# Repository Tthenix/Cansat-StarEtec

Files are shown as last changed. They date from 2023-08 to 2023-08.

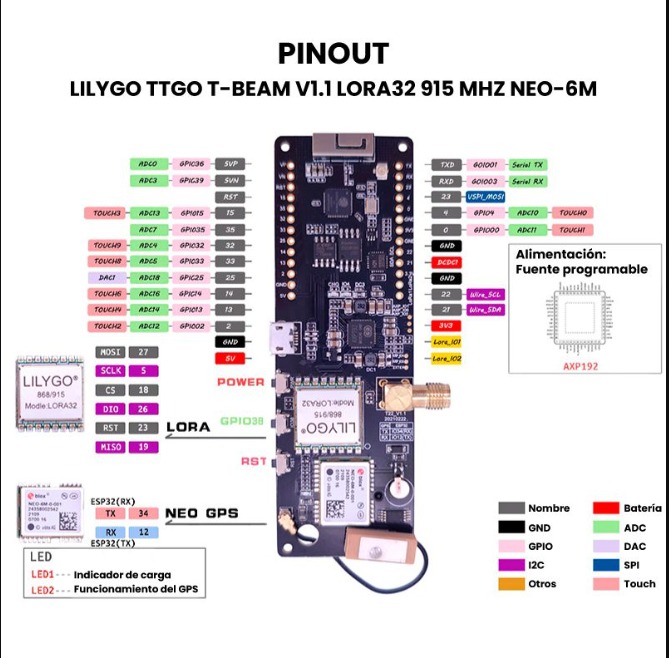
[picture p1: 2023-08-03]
T-beam/lilygo T beam documentos/Lilygo T beam Pinout.jpg

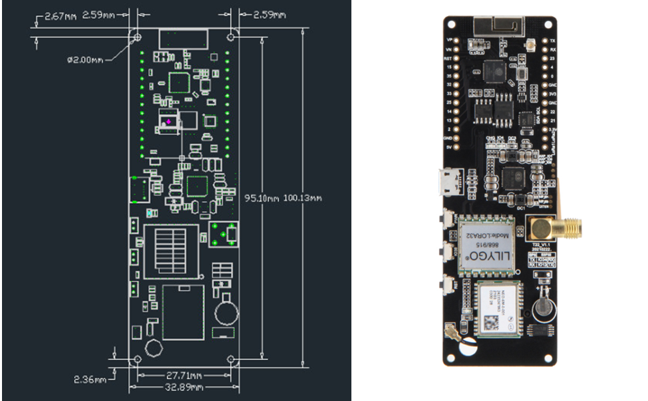
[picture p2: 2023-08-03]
T-beam/lilygo T beam documentos/size_LilygoTbeam.jpg

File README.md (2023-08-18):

# Cansat StarEtec

¡Bienvenido al repositorio del proyecto Cansat StarEtec! Este proyecto trata sobre la construcción y lanzamiento de un Cansat, que es una simulación de una misión espacial en una lata. Este repositorio contiene el código, el diseño y la documentación relacionados con el proyecto. El mismo es fue desarrollado por estudiantes del colegio técnico de la Universidad de Mendoda (UM), también conocido cómo ETec.
Para más información puede acercarse por la pagina web del proyecto [en google sites](https://sites.google.com/alumno.etec.um.edu.ar/cansat-2023/inicio)

## Descripción del Proyecto

El objetivo principal de este proyecto es desarrollar y lanzar con éxito un Cansat, recopilando datos y realizando diferentes experimentos durante su descenso desde una cierta altura. Estos son los aspectos clave del proyecto:

- Diseño y construcción del hardware del Cansat.
- Desarrollo del código necesario para la recopilación de datos y el control del Cansat.
- Pruebas y ajustes del Cansat antes del lanzamiento.
- Lanzamiento y recopilación de datos durante el descenso.
- Análisis de los datos y conclusiones obtenidas.

## Estructura del Repositorio

El repositorio está organizado de la siguiente manera:

- `docs/`: Esta carpeta contiene la documentación del proyecto, incluyendo manuales, guías y otros recursos útiles.
- `T-beam/`: Aquí encontrarás el código fuente relacionado con la parte encargada de recopilar información del medio y enviarla.
- `diseño3D/`: Contiene los diseños 3D del Cansat.
- `esp32cam_usd_uart/`: Aquí encontrarás el código fuente relacionado el sistema de recopilación de imágenes.
- `receiver_Heltec/`: Aquí encontrarás el código fuente relacionado con la parte encargada de recopilar información enviada y copmunicarse con el ordenador.
- `script/`: Aquí encontrarás el código fuente relacionado con la parte encargada de interpretar los datos, mostrarlos y guardarlos en archivos .csv convenientes.

## Cómo Contribuir

¡Agradecemos tus contribuciones al proyecto! Si deseas contribuir, puedes seguir estos pasos:

1. Haz un `fork` de este repositorio.
2. Clona tu fork en tu máquina local: `git clone https://github.com/TuUsuario/Cansat-StarEtec.git`
3. Crea una nueva rama para tu contribución: `git checkout -b nueva-funcionalidad`
4. Realiza tus cambios y mejoras.
5. Realiza commits con mensajes descriptivos: `git commit -m "Añadida nueva funcionalidad: X"`
6. Sube tus cambios a tu fork: `git push origin nueva-funcionalidad`
7. Abre un Pull Request en este repositorio.

## Contacto

Si tienes preguntas, sugerencias o comentarios, puedes ponerte en contacto con nosotros visitando [nuestra pagina web](https://sites.google.com/alumno.etec.um.edu.ar/cansat-2023/inicio).
También están los siguientes correos:
- Docente Colaborador: [`Mario Stefano Papetti Funes`](mailto:mario.papetti@etec.um.edu.ar).
- Docente Colaborador: [`Gema Pont`](mailto:maria.pont@etec.um.edu.ar).
- Alumno Colaborador: [`Nahuel Quiroga`](mailto:n.quiroga@alumno.etec.um.edu.ar).
- Integrante de equipo: [`Mercedes Marón`](mailto:m.maron@alumno.um.edu.ar).
- Integrante de equipo: [`Santiago Juárez`](mailto:sc.juarez@alumno.etec.um.edu.ar).
- Integrante de equipo: [`Mateo Molina`](mailto:mn.molina@alumno.etec.um.edu.ar).

---

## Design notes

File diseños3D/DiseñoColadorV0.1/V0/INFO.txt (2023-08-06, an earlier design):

By:Lucas Adriano Perinetti
Primer diseño
Ventajas: Resistente
Desventajas: Pesa demasiado, No se tuvo en cuenta el BMP280

Las ideas partieron de un diseño cilindrico el cual se armo y se le hicieron ajugueros para los sensores, tambien se diseño una tapa para el cilindro y una estructura interna

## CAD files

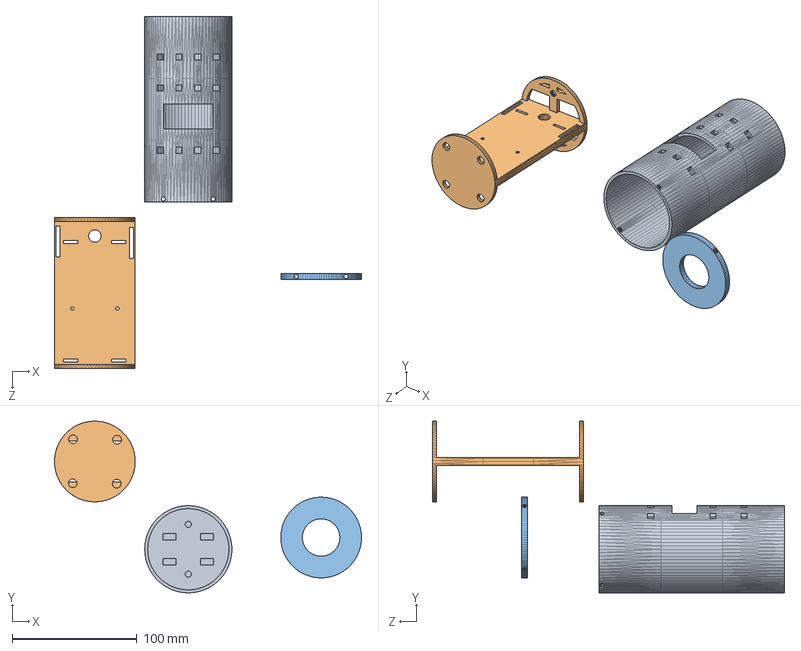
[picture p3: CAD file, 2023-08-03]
diseños3D/v0-4/Ensamblaje.SLDASM
246.5 x 137.8 x 282.7 mm
Envase
Interior
Tapa

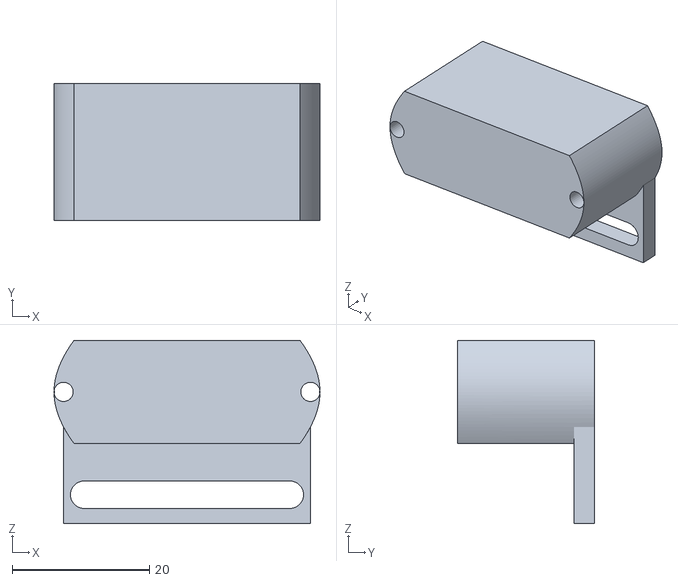
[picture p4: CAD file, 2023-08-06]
diseños3D/DiseñoColadorV0.1/V2/Soporte Lidar Y Ov7670 .stl
38.8 x 20.0 x 26.7

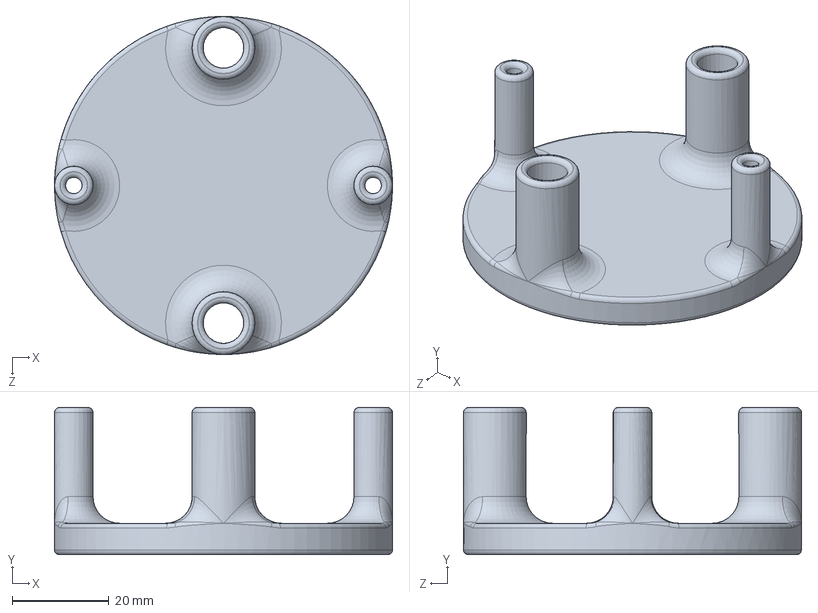
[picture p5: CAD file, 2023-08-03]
diseños3D/v0-3/Base.SLDPRT
70.0 x 30.5 x 70.0 mm

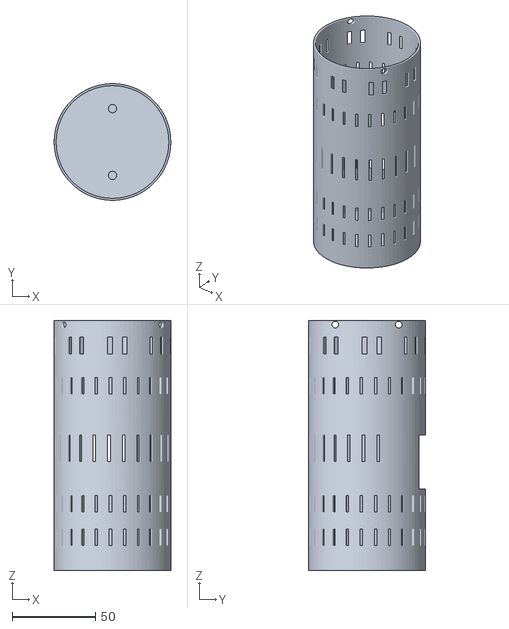
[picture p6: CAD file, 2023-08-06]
diseños3D/DiseñoColadorV0.1/V2/Envase.stl
70.0 x 70.0 x 150.0

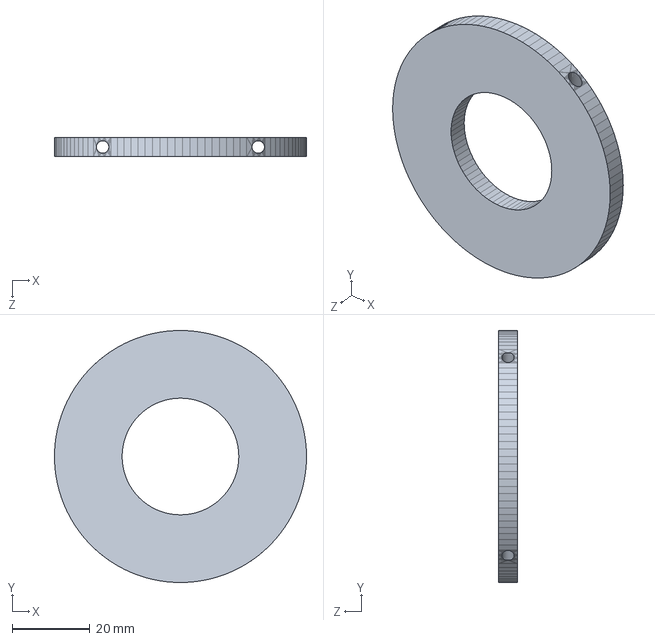
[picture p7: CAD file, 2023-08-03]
diseños3D/v0-4/Tapa.SLDPRT
64.8 x 64.8 x 5.00 mm

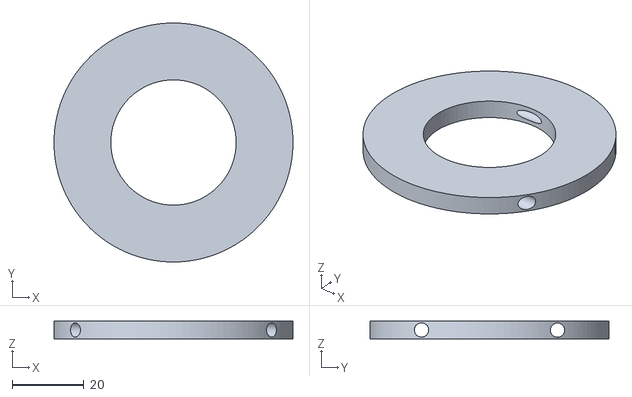
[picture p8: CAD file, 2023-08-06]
diseños3D/DiseñoColadorV0.1/V2/Tapa.stl
66.8 x 66.8 x 5.00

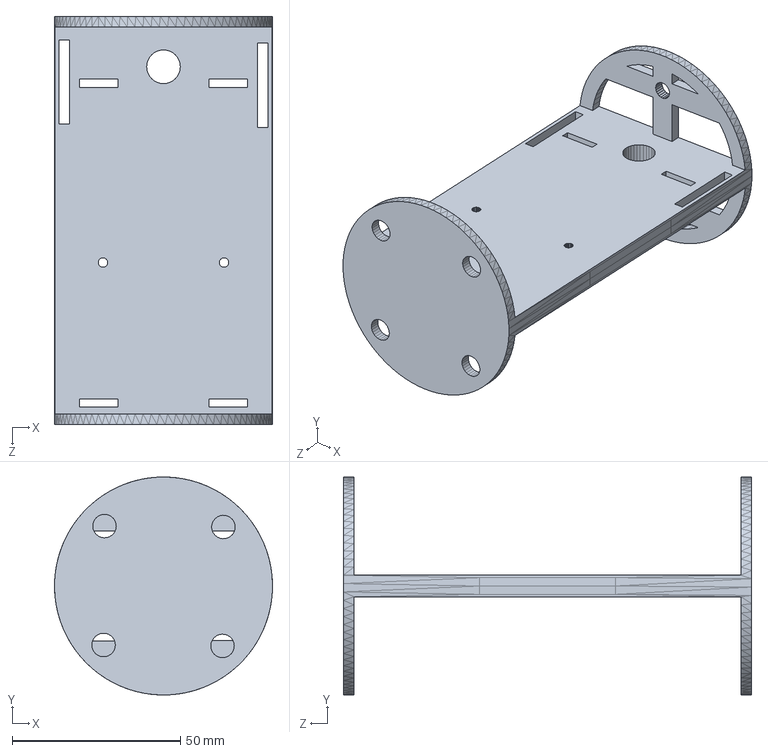
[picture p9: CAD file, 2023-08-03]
diseños3D/v0-4/Interior.SLDPRT
64.8 x 64.8 x 121.4 mm

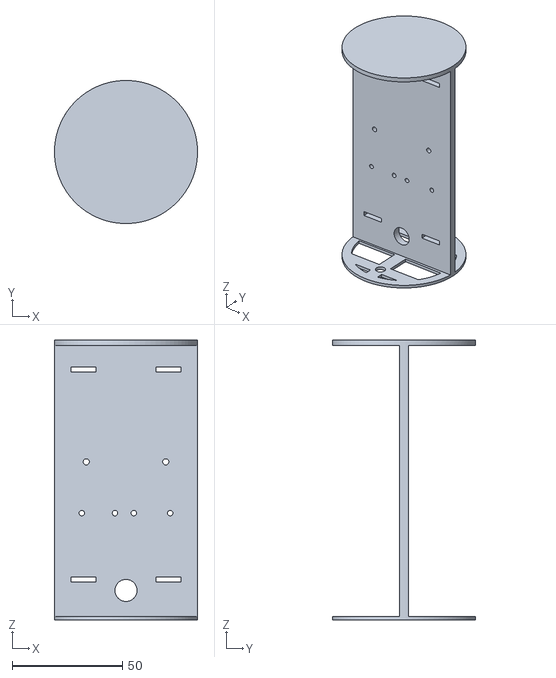
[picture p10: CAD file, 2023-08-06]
diseños3D/DiseñoColadorV0.1/V2/Interno.stl
64.8 x 64.8 x 126.8

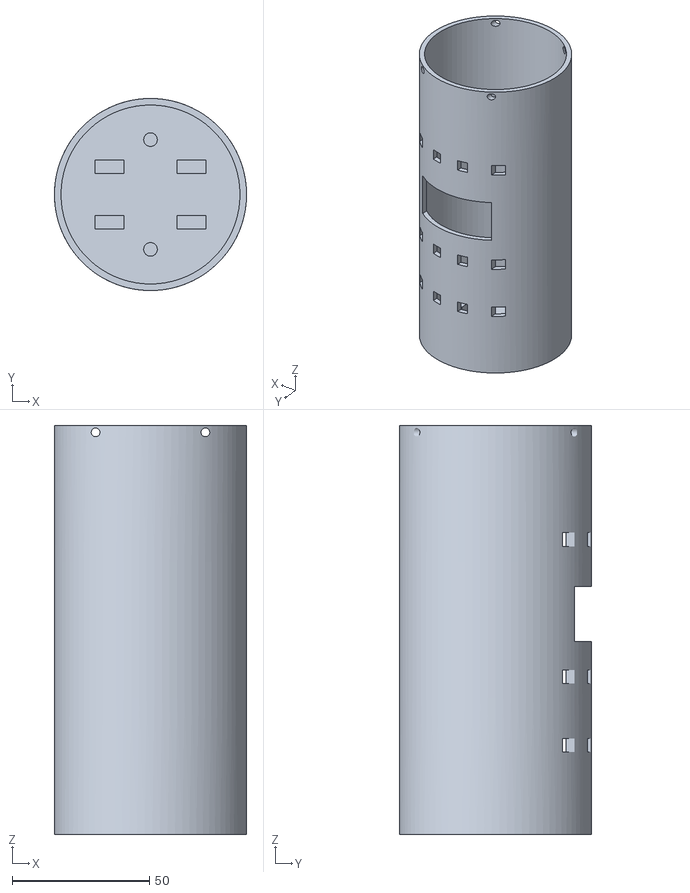
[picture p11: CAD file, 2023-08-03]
diseños3D/v0-4/Envase.stl
70.0 x 70.0 x 149.0

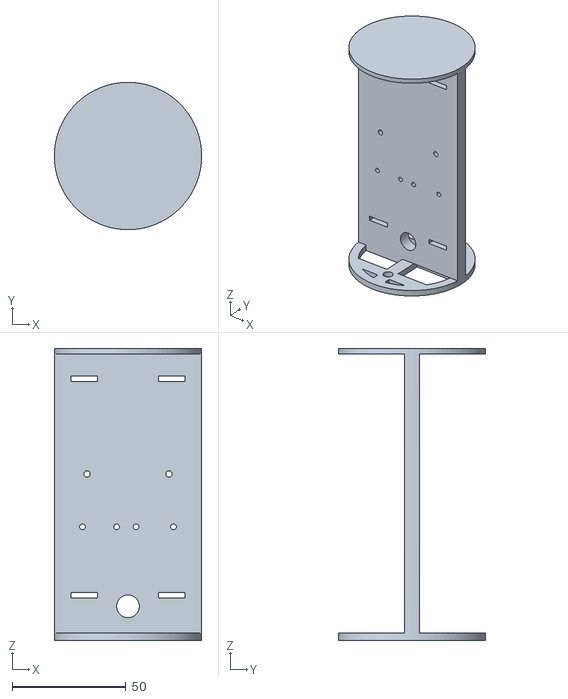
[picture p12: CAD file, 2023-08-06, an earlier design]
diseños3D/DiseñoColadorV0.1/V0/Interior.stl
64.8 x 64.8 x 128.4

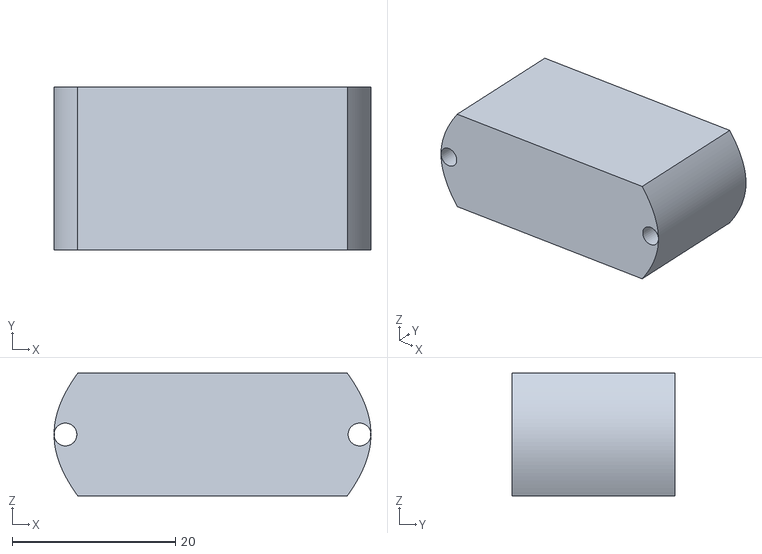
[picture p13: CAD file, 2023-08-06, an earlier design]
diseños3D/DiseñoColadorV0.1/V0/Soporte para el lidarr.stl
38.8 x 20.0 x 15.0

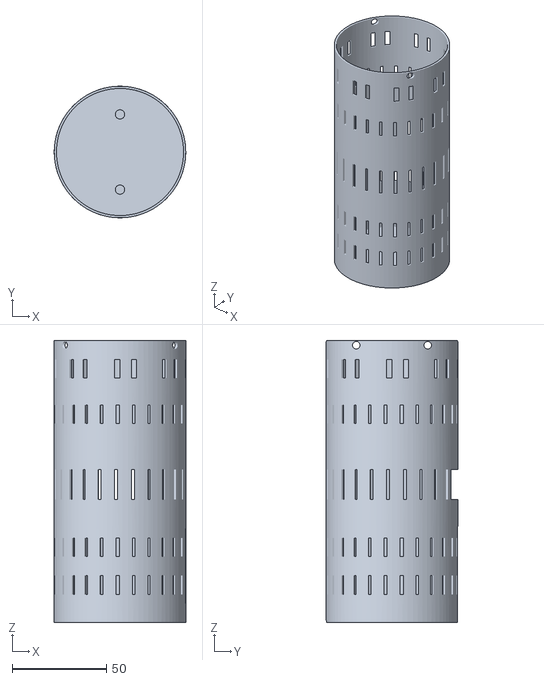
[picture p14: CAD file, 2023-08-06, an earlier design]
diseños3D/DiseñoColadorV0.1/V1/envase.stl
70.0 x 70.0 x 150.0

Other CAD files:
diseños3D/DiseñoColadorV0.1/V0/Envase.stl
diseños3D/DiseñoColadorV0.1/V0/TAPA.stl
diseños3D/v0-3/Base.STL
diseños3D/v0-4/Interior.stl
diseños3D/v0-4/Tapa.stl

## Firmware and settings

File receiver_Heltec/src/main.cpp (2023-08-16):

#include <Arduino.h>

//Libraries for LoRa
#include <SPI.h>
#include <LoRa.h>
//Libraries for OLED Display
#include <Wire.h>
#include <Adafruit_GFX.h>
#include <Adafruit_SSD1306.h>

//define el sd
#include <SD.h>
File dataFile;

//  SPI port #2:  SD  Card Adapter
#define  SD_CLK      5
#define  SD_MISO    19
#define  SD_MOSI    27
#define  SD_CS      12

//  SPI port:  LoRa (SX1278) 
//       LoRa      Pin
#define  LoRa_SCK    5
#define  LoRa_MISO  19
#define  LoRa_MOSI  27
#define  LoRa_CS    18
#define  LoRa_RST   14    //  LoRa_Reset
#define  LoRa_DIO0   26    //  LoRa_IRQ


//433E6 for Asia
//866E6 for Europe
//915E6 for North America
#define BAND 866E6


//OLED pins
#define OLED_SDA 4
#define OLED_SCL 15
#define OLED_RST 16
#define SCREEN_WIDTH 128 // OLED display width, in pixels
#define SCREEN_HEIGHT 64 // OLED display height, in pixels

//  OLED screen text rows:
#define  row1     0     //  y=0 is top row of size 1 text
#define  row2    10
#define  row3    20
#define  row4    30
#define  row5    40
#define  row6    50     //  row7 at 70 is too low

Adafruit_SSD1306 display(SCREEN_WIDTH, SCREEN_HEIGHT, &Wire, OLED_RST);

String LoRaData;

#define  Select    LOW   //  Low CS means that SPI device Selected
#define  DeSelect  HIGH  //  High CS means that SPI device Deselected

void setup() { 
  //Pines ChipSelect de los perifericos
  pinMode(SD_CS, OUTPUT);
  pinMode(LoRa_CS, OUTPUT);
  digitalWrite(LoRa_CS, DeSelect);
  //reset OLED display via software
  pinMode(OLED_RST, OUTPUT);
  digitalWrite(OLED_RST, LOW);
  delay(20);
  digitalWrite(OLED_RST, HIGH);
 
  Serial.begin(115200);
  while(!Serial);                     //  wait to connect to computer

  //initialize OLED
  Wire.begin(OLED_SDA, OLED_SCL);
  if(!display.begin(SSD1306_SWITCHCAPVCC, 0x3c, false, false)) { // Address 0x3C for 128x32
    Serial.println(F("SSD1306 allocation failed"));
    for(;;); // Don't proceed, loop forever
  }

  display.clearDisplay();
  display.setTextColor(WHITE);
  display.setTextSize(1);
  display.setCursor(0,0);
  display.print("LORA RECEIVER ");
  display.display();

  display.clearDisplay();
  display.setTextColor(WHITE);

  // // Inicializar SD
  // SPI.begin(SD_CLK, SD_MISO, SD_MOSI, SD_CS);  // Inicializar SPI para SD
  
  // // Inicializar la tarjeta microSD
  // digitalWrite(SD_CS, Select);    //  SELECT (Low) SD Card SPI
  // if (!SD.begin(SD_CS)) {
  //   Serial.println("Error al inicializar la tarjeta microSD.");
  //   display.setCursor(0,0);
  //   display.print("[ERROR] init SD");
  //   return;
  // }
  
  // Serial.println("Tarjeta microSD inicializada correctamente.");
  // // Verificar si el archivo ya existe, si no, crearlo con los encabezados
  // display.setCursor(0,0);
  // display.print("Módulo SD");
  // display.setCursor(0,20);
  // const char* fileName = "/datos.csv";
  // if (!SD.exists("datos.csv")) {
  //   File dataFile = SD.open("datos.csv", FILE_WRITE);
  //   if (dataFile) {
  //     dataFile.println("pin,humedad,temp1,corriente,temp2"); // Encabezados
  //     dataFile.close();
  //     Serial.println("Archivo datos.csv creado con encabezados.");
  //     display.print("Se ha creado: datos.csv");
  //   } else {
  //     Serial.println("Error al crear el archivo datos.csv.");
  //     display.print("[Error] crear: datos.csv");
  //   }
  // } else {
  //   Serial.print("el archivo ya existe");
  //   display.print("Tiene archivo datos.csv");
  // }
  // display.display();  
  // digitalWrite(SD_CS, DeSelect);    //  DESELECT (high) SD Card SPI
  // SPI.end();

  delay(1500);

  Serial.println("LoRa Receiver Test");
 
  //SPI LoRa pins
  SPI.begin(LoRa_SCK, LoRa_MISO, LoRa_MOSI, LoRa_CS);
  //setup LoRa transceiver module
  LoRa.setPins(LoRa_CS, LoRa_RST, LoRa_DIO0);
  digitalWrite(LoRa_CS, Select);   //  SELECT (low) LoRa SPI 
  if (!LoRa.begin(BAND)) {
    Serial.println("Starting LoRa failed!");
    while (1);
  }

  Serial.println("LoRa Initializing OK!");
  display.setCursor(0,10);
  display.println("LoRa Init OK!");
  display.display();  
  SPI.end();
  
}

void loop() {

  //try to parse packet
  //  use the LoRa
  SPI.begin( LoRa_SCK, LoRa_MISO, LoRa_MOSI, LoRa_CS );
  LoRa.setPins( LoRa_CS, LoRa_RST, LoRa_DIO0);
  digitalWrite(SD_CS, DeSelect);    //  deselet SD Card SPI
  digitalWrite(LoRa_CS, Select);    //  SELECT (low) LoRa SPI 

  int packetSize = LoRa.parsePacket();
  bool dataRead = true;

  if (packetSize) {
    dataRead = false;
    //received a packet
    Serial.print("Received packet ");

    //read packet
    while (LoRa.available()) {
      LoRaData = LoRa.readString();
      Serial.print(LoRaData);
    }

    //print RSSI of packet
    int rssi = LoRa.packetRssi();
    Serial.print(" with RSSI ");    
    Serial.println(rssi);

    // Dsiplay information
    display.clearDisplay();
    display.setCursor(0,0);
    display.print("Cansat StarETec");
    display.setCursor(0,20);
    display.print("Mensaje recibido:");
    display.setCursor(0,30);
    display.print(LoRaData);
    display.setCursor(0,40);
    display.print("RSSI:");
    display.setCursor(30,40);
    display.print(rssi);
    display.display();  
    
    digitalWrite(LoRa_CS, DeSelect);    //  deselet SD Card SPI
    SPI.end();
  }

  // if(!dataRead){
  //   SPI.begin(SD_CLK, SD_MISO, SD_MOSI, SD_CS);  // Inicializar SPI para SD    
  //   // Inicializar la tarjeta microSD
  //   digitalWrite(SD_CS, Select);    //  SELECT (Low) SD Card SPI
  //   if (!SD.begin(SD_CS)){
  //     // Procesar el string y reemplazar '\n' con comas
  //     LoRaData.replace("\n", ",");

  //     // Abrir el archivo en modo anexar
  //     File dataFile = SD.open("datos.csv", FILE_APPEND);
  //     if (dataFile) {
  //       dataFile.println(LoRaData);
  //       dataFile.close();
  //       Serial.println("Datos escritos en 'datos.csv'.");
  //     } else {
  //       Serial.println("Error al abrir el archivo 'datos.csv'.");
  //     }

  //   }
  //   //  done using the SD Card
  //   digitalWrite(SD_CS, DeSelect);    //  DESELECT (high) SD Card SPI
  //   SD.end();
  //   dataRead = true;
  // }
  delay(500);
}

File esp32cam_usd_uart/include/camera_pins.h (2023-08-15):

// camera_pins.h
// #define PWDN_GPIO_NUM     -1
// #define RESET_GPIO_NUM    -1
// #define XCLK_GPIO_NUM     21
// #define SIOD_GPIO_NUM     26
// #define SIOC_GPIO_NUM     27

// #define Y9_GPIO_NUM       35
// #define Y8_GPIO_NUM       34
// #define Y7_GPIO_NUM       39
// #define Y6_GPIO_NUM       36
// #define Y5_GPIO_NUM       19
// #define Y4_GPIO_NUM       18
// #define Y3_GPIO_NUM        5
// #define Y2_GPIO_NUM        4
// #define VSYNC_GPIO_NUM    25
// #define HREF_GPIO_NUM     23
// #define PCLK_GPIO_NUM     22


#if defined(CAMERA_MODEL_AI_THINKER)
#define PWDN_GPIO_NUM  32
#define RESET_GPIO_NUM -1
#define XCLK_GPIO_NUM  0
#define SIOD_GPIO_NUM  26
#define SIOC_GPIO_NUM  27
#define Y9_GPIO_NUM    35
#define Y8_GPIO_NUM    34
#define Y7_GPIO_NUM    39
#define Y6_GPIO_NUM    36
#define Y5_GPIO_NUM    21
#define Y4_GPIO_NUM    19
#define Y3_GPIO_NUM    18
#define Y2_GPIO_NUM    5
#define VSYNC_GPIO_NUM 25
#define HREF_GPIO_NUM  23
#define PCLK_GPIO_NUM  22

// 4 for flash led or 33 for normal led
#define LED_GPIO_NUM       4

#else
#error "Camera model not selected"
#endif

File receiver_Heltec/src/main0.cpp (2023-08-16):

//
// Heltec 32 LoRa OLED (with SD Card)
//               ______________
//          Gnd |    |  USB|   | Gnd
//           5v |    | port|   |  5v
//          3v3 |    |_____|   | 3v3
//          Gnd |      ALL     |  36<-     <- : Input Only!
//           Rx |     GPIO     |  37<-
//           Tx |     3.3v     |  38<-
//          RST |   ________   |  39<-
//            0 |  |        |  |  34<-
//    (SCL)  22 |  |        |  |  35<-
// SPI MISO  19 |  |        |  |  32<-
//           23 |  |        |  |  33<-
//LoRa CS(HI)18 |  |        |  |  25  (LED)
// SPI SCK    5 |  |  OLED  |  |  26  LoRa IRQ
//OLED SCL   15 |  |        |  |  27  SPI MOSI
//            2 |  |        |  |  14  LoRa Rst
//OLED SCA    4 |  |        |  |  12
//           17 |  |________|  |  13
//OLED RST   16 |______________|  21  (SD_CS)
//

#include <mySD.h>        //  SD Card (VMA304)
#include "SSD1306.h"     //  OLED
#include <LoRa.h>        //  LoRa

File root;

//       OLED       Pin
#define  SDA          4   //  Serial Data
#define  SCL         15   //  Serial Clock
#define  oRST        16   //  Reset
#define  OLED_ADDR 0x3C   //  OLED display TWI address

SSD1306         display(OLED_ADDR, SDA, SCL);
//  OLED screen text rows:
#define  row1     0     //  y=0 is top row of size 1 text
#define  row2    10
#define  row3    20
#define  row4    30
#define  row5    40
#define  row6    50     //  row7 at 70 is too low

//  SPI port #2:  SD Card Adapter
#define  SD_CLK      5
#define  SD_MISO    19
#define  SD_MOSI    27
#define  SD_CS      21

//  SPI port:  LoRa (SX1278) 
//       LoRa      Pin
#define  LoRa_SCK    5
#define  LoRa_MISO  19
#define  LoRa_MOSI  27
#define  LoRa_CS    18
#define  LoRa_RST   14    //  LoRa_Reset
#define  DI0        26    //  LoRa_IRQ
#define  BAND    915E6    //  other freq: 433E6  // or ? LoRa f(MHz)

#define  Select    LOW   //  Low CS means that SPI device Selected
#define  DeSelect  HIGH  //  High CS means that SPI device Deselected

File     sessionFile;   //  SD card filenames are restricted to 8 characters + extension

int counter = 0;        //  count sent LoRa messages

/***********************************************************/
void setup(){  
  // set output pins
  pinMode(oRST,OUTPUT);
  pinMode(SD_CS,OUTPUT);
  pinMode(LoRa_CS,OUTPUT);
  digitalWrite(LoRa_CS, DeSelect);

  // set GPIO16 Low then High to Reset OLED
  digitalWrite(oRST, LOW);  
  delay(50);
  digitalWrite(oRST, HIGH);

  Serial.begin(115200);
  while(!Serial);                     //  wait to connect to computer

  display.init();
  display.flipScreenVertically();
  display.setFont(ArialMT_Plain_10);
  display.setTextAlignment(TEXT_ALIGN_LEFT);
  display.clear();
  display.display();

  Serial.print("Initializing SD card...");
  digitalWrite(SD_CS, Select);    //  SELECT (Low) SD Card SPI
  if (!SD.begin( SD_CS, SD_MOSI, SD_MISO, SD_CLK )) {
    Serial.println("initialization failed!");
    //  now what?
  } else {
    Serial.println("initialization done.");
    display.drawString( 5,row1,"SD Card OK!" );
    display.display();
    delay(1000);
  }
  /* open "test.txt" for writing */
  root = SD.open("test.txt", FILE_WRITE);
  if (root) {
    root.println("Hello world!");
    root.flush();
    root.close();
  } else {    //  file open error
    Serial.println("error opening test.txt");
  }
  display.drawString( 5,row2,"Wrote in test.txt" );
  display.display();
  delay(100);
  /* after writing, then reopen the file and read it */
  root = SD.open("test.txt");
  if (root) {    /* read from the file to the end of it */
    while (root.available()) {  // read the file
      Serial.write(root.read());
    }
    root.close();
  } else {
    Serial.println("error opening test.txt");
  }
  display.drawString( 5,row3,"Read from test.txt" );
  display.display();
  delay(100);
  //  done testing the SD Card
  digitalWrite(SD_CS, DeSelect);    //  DESELECT (high) SD Card SPI
  SD.end();
  delay( 100 ); 

  //  now test the LoRa

  SPI.begin( LoRa_SCK, LoRa_MISO, LoRa_MOSI, LoRa_CS );

  LoRa.setPins( LoRa_CS, LoRa_RST, DI0 );
  digitalWrite(LoRa_CS, Select);   //  SELECT (low) LoRa SPI 
  Serial.println("LoRa Sender");
  if (!LoRa.begin(BAND)) {
    Serial.println("Starting LoRa failed!");
    display.drawString( 5, row4, "LoRa Init Failed!");
    display.display();
    // now what?
  } else {
    Serial.println("LoRa Initial OK!");
    display.drawString( 5, row4, "LoRa Initialized OK!");
    display.display();
    delay(1000);
  }
  Serial.println("Setup done!");
}

void loop() {
  Serial.print("Sending packet: ");
  Serial.println(counter);
  display.clear();
  display.setFont(ArialMT_Plain_16);
  display.drawString(3, 5, "Sending packet ");
  display.drawString(50, 30, String(counter));
  display.display();
  // send packets
  LoRa.beginPacket();
  LoRa.print("Hi. Sent packet #");
  LoRa.print(counter);
  LoRa.endPacket();
  counter++;
  delay(500);
}

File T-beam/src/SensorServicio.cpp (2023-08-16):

#include "../include/SensorServicio.hpp"
#include <Wire.h>
#include "AXP192.h"

SensorServicio::SensorServicio() : dht(DHTPIN, DHTTYPE), TFminiSerial(TFMINI_TX_PIN, TFMINI_RX_PIN), gpsSerial(GPS_TX_PIN, GPS_RX_PIN)
{

  // Se definen parametros de seteo para MQ7
  mq7Pin = 14; // Defino el pin donde estará el sensor MQ7
  mq7Offset = 0.0;
  mq7MaxPPM = 5.0;
  mq7MaxValue = 1023.0;

  // Ajuste de la zona horaria local (UTC-3 para Mendoza, Argentina)
  timeZoneOffset = -3;

  // Se definen parametros de seteo para AXP192
  deltaT = 1.0;
}

void SensorServicio::begin()
{
  gpsSerial.begin(9600); // Inicia la comunicación con el GPS
  Serial.begin(SerialUsb_BAUDRATE);
  dht.begin();

  // M5.begin(false, true, false);
  axp.begin();

  // BMP init
  unsigned status;
  status = bmp.begin(BMP280_ADDRESS_new);
  if (!status)
  {
    Serial.println(F("Could not find a valid BMP280 sensor, check wiring or "
                     "try a different address!"));
    Serial.print("SensorID was: 0x");
    Serial.println(bmp.sensorID(), 16);
    Serial.print("        ID of 0xFF probably means a bad address, a BMP 180 or BMP 085\n");
    Serial.print("        ID of 0x56-0x58 represents a BMP 280,\n");
    Serial.print("        ID of 0x60 represents a BME 280.\n");
    Serial.print("        ID of 0x61 represents a BME 680.\n");
    while (1)
      delay(10);
  }

  /* Default settings from the datasheet. */
  bmp.setSampling(Adafruit_BMP280::MODE_FORCED,  /* Operating Mode. */
                  Adafruit_BMP280::SAMPLING_X8,  /* Temp. oversampling */
                  Adafruit_BMP280::SAMPLING_X16, /* Pressure oversampling */
                  Adafruit_BMP280::FILTER_X16);  /* Standby time. */

  TFminiSerial.begin(TFMINI_BAUDRATE);
  delay(4000);
  TFmini.begin(&TFminiSerial);
}

void SensorServicio::leerSensores()
{
  //*** MQ7 values ***/
  //    Para revisar, calibración y medidas del COppm
  // CO_ppm = (AnalogValue - Offset) * (MaxPPM / (MaxValue - Offset))

  mq7COppm = (analogRead(mq7Pin) - mq7Offset) * (mq7MaxPPM / (mq7MaxValue - mq7Offset));
  mq7VoltageValue = analogRead(mq7Pin) * (3.3 / 1023.0);

  //*** AXP192 values ***/
  vbat = axp.GetBatVoltage();
  vaps = axp.GetAPSVoltage();
  icharge = axp.GetBatCurrent();
  idischarge = axp.GetBatChargeCurrent();
  tempAXP192 = axp.GetTempInAXP192();

  // Leer el tiempo transcurrido desde el último ciclo de bucle en segundos
  // float deltaT = 1.0; // Ajusta este valor según la frecuencia de lectura
  float current;
  if ((idischarge <= 0) && (icharge > 0))
  {
    current = icharge;
  }
  else if ((idischarge > 0) && (icharge <= 0))
  {
    current = idischarge;
  }
  else
  {
    current = 0;
  }
  mAh = (current) * (deltaT / 3600.0);

  //*** DHT values ***/
  dhtHum = dht.readHumidity();
  dhtTemp = dht.readTemperature();
  dhtTempF = dht.readTemperature(true);

  // must call this to wake sensor up and get new measurement data
  // it blocks until measurement is complete
  if (bmp.takeForcedMeasurement())
  {
    //*** BMP values ***/
    bmpTemp = bmp.readTemperature();
    bmpPres = bmp.readPressure() / 100; // dividir por 100 para tener hPa
    bmpAlti = bmp.readAltitude(1013.25);
  }

  // /*** TFmini values ***/
  this->getTFminiData();

  /*** NEO6M values ***/
  this->readGPS();
}

void SensorServicio::mostrarValores()
{

  Serial.println("###########################");
  Serial.println("|IMPRESIÓN DE DATOS LEIDOS|");
  Serial.println("###########################");

  Serial.println("Sensor MQ7");

  Serial.print("\tPin: ");
  Serial.println(mq7Pin);
  Serial.print("\tVoltaje: ");
  Serial.print(mq7VoltageValue);
  Serial.println(" V");
  Serial.print("\tPartes por millon de CO: ");
  Serial.print(mq7COppm);
  Serial.println(" COppm");

  Serial.println("-----------------------------------------------");
  Serial.println("Sensor AXP192");

  Serial.print("\tVbat: ");
  Serial.print(vbat, 3);
  Serial.print(" V");
  Serial.print("\t|  Vaps: ");
  Serial.print(vaps, 3);
  Serial.println(" V");
  Serial.print("\tIcharge: ");
  Serial.print(icharge, 3);
  Serial.print(" mA");
  Serial.print("\t|  Idischarge: ");
  Serial.print(idischarge, 3);
  Serial.println(" mA");
  Serial.print("\tTemperatura: ");
  Serial.print(tempAXP192);
  Serial.print(" °C");
  Serial.print("\t|  Consumo: ");
  Serial.print(mAh, 3);
  Serial.println(" mA/h");

  Serial.println("-----------------------------------------------");
  Serial.println("Sensor DHT11");

  Serial.print("\tHumedad DHT: ");
  Serial.print(dhtHum);
  Serial.println(" %t");
  Serial.print("\tTemperatura DHT: ");
  Serial.print(dhtTemp);
  Serial.println(" *C ");
  Serial.print("\tTemperatura (°F) DHT: ");
  Serial.print(dhtTempF);
  Serial.println(" *F");

  Serial.println("-----------------------------------------------");
  Serial.println("Sensor BMP280");

  Serial.print("\tPresión BMP: ");
  Serial.print(bmpPres);
  Serial.println(" hPa");
  Serial.print("\tTemperatura BMP: ");
  Serial.print(bmpTemp);
  Serial.println(" *C ");
  Serial.print("\tAltitud BMP: ");
  Serial.print(bmpAlti);
  Serial.println(" m");

  Serial.println("-----------------------------------------------");
  Serial.println("Sensor TFmini");

  Serial.print("\tDistancia promedio: ");
  Serial.print(TFdistanceAverage);
  Serial.println(" cm");
  Serial.print("\tFortaleza de Señal: ");
  Serial.println(TFstrength);

  Serial.println("-----------------------------------------------");
  Serial.println("Sensor Neo6-M");

  Serial.print("\tLatitud: ");
  Serial.println(gpsLatitude, 6);
  Serial.print("\tLongitud: ");
  Serial.println(gpsLongitude, 6);
  Serial.print("\tAltitud GPS: ");
  Serial.print(gpsAltitude);
  Serial.println(" metros");
  Serial.print("\tVelocidad: ");
  Serial.print(gpsSpeed);
  Serial.println(" km/h");
  Serial.print("\tFecha: ");
  Serial.print(gpsDay);
  Serial.print("/");
  Serial.print(gpsMonth);
  Serial.print("/");
  Serial.print(gpsYear);
  Serial.print("\t|  Hora: ");
  Serial.print(gpsHour);
  Serial.print(":");
  Serial.print(gpsMinutes);
  Serial.print(":");
  Serial.println(gpsSeconds);
  if (gpsSerial.available())
  {
    this->readGPS();
  }
  else
  {
    Serial.println("%%%%  GPS Serial not available!  %%%");
  }
}
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

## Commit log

2023-08-01 se cargaron todas las dependencias en framework
2023-08-03 Se agregó documentación del tbeam y clases Lora y Sensores
2023-08-03 Se agregaron los diseños 3D
    [Base.SLDPRT, Base.STL, Ensamblaje.SLDASM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]
2023-08-06 Se implementó BMP280, TFmini y Neo6-M además de mejoras menores
2023-08-06 Se reparó el método de envío por LoRa para el vector de datos. Falta prueba física.
2023-08-07 Probando GPS que funciona de otro programa
2023-08-08 Funciona Neo6-M, revisar temperatura BMP280, voltaje MQ7 y consumo del AXP192
2023-08-09 Se arregló el BMP280, peusto en forcedMode
    [SensorServicio.cpp, SensorServicio.hpp]
2023-08-11 Se cambió pin DHT y mejoras menores
2023-08-11 sensores andando joiaa y midiendo
2023-08-12 Se avanzó con la comunicación por medio del lora
2023-08-15 se cargó programa del esp32cam
    Se agrega el directorio de trabajo con platformio del ESP32 S CAM AI-Thinker usado para poder realizar las capturas de imágenes y almacenarlas en su memoria micro SD.
    no se logró por cuestiones de tiempo la implementación de una comunicación UART con el mismo para que además guarde los datos de los sensores del T-beam, se deja como posible implementación a futuro.
2023-08-16 bmp280 configuracion y arreglos
    [SensorServicio.cpp, SensorServicio.hpp, main.cpp]
2023-08-16 Se optó por el Plan C - Script en python
2023-08-16 Se realizaron las pruebas y formateo de datos .csv
